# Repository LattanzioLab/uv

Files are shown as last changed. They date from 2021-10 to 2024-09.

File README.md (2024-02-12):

# Active regulation of Ultraviolet (UV) light by wildlife
Collection of materials relevant to our ongoing research testing hypotheses about UV light regulation in reptiles. 

In brief, almost a century of ecological and evolutionary studies have established the importance of daily behaviors like basking and shuttling (movements between sun and shade) by lizards and other ectotherms for maintaining thermal homeostasis. That is, for regulating their internal body temperatures. In fact, those behaviors have become synonymous with temperature regulation--so much that they are putatively referred to as 'thermoregulatory behavior.' 

Put differently, an assumption underlying approaches thus far is that the only important function of those behaviors is temperature regulation. Aside from a few studies aimed at a zoo-based audience, consideration for the importance of other functions, has remained ignored. Our goal is to promote appreciation and further study of one function in particular: <b><i>regulation of UV light exposure. </b></i>

<b>Why UV?</b>

UV exposure stimulates endogenous production of vitamin D3 (Holick et al. 1995). Lizard skin contains the precursor for vitamin D3, and initiation of the conversion process requires sun exposure (Holick et al. 1995), and the amount of vitamin D3 produced depends on the extent of UV exposure (Karsten et al. 2009). The importance of maintaining appropriate circulating vitamin D3 levels extends to multiple fitness-relevant considerations, including bone development, organ function, embryogenesis and eggshell development, to name a few (Stumpf 1988; Laing and Fraser 1999; Ferguson et al. 1996). For example, in a pivotal study by Ferguson et al. (1996) on panther chameleons (Furcifer pardalis), only females that were provided access to sufficient UV light sources produced eggs that developed to term and hatched successfully. Although reptiles can also obtain vitamin D3 via ingestion, efficacy of increasing the circulating concentration of vitamin D3 is greatest with solar UV exposure (Acierno et al. 2006); dietary D3 supplements alone are insufficient (Ferguson et al. 1996). At the same time, just as with temperature, prolonged exposure to extreme UV levels can be lethal (Ferguson et al. 1996). These considerations support that regulation of UV exposure within an optimal range should be adaptive. 

We capitalize on a classic framework (Hertz et al. 1993) for evaluating active temperature regulation in ectotherms ("cold-blooded" animals), Arduino-based electronic sensors and other components, and our lab's 3D printer, to study active UV regulation in those species. 

Please reach out if you have any questions about the materials in this repository, and also make sure to follow license and attribution guidance too (see LICENSE files); and cite this repository and related publications in your works. Thanks so much!  

Cheers,
The Lattanzio Lab

<b>  </b>
<b>REFERENCES</b>

Acierno, M.J., Mitchell, M.A., Roundtree, M.K., Zachariah, T.T. (2006). Effects of ultraviolet radiation on 25-hydroxyvitamin D3 synthesis in red-eared slider turtles (Trachemys scripta elegans). American Journal of Veterinary Research. 67:2046-2049. 

Ferguson, G.W., Jones, J.R., Gehrmann, W.H., Hammack, S.H., Talent, L.G., Hudson, R.D., Dierenfeld, E.S., Fitzpatrick, M.P., Frye, F.L., Holick, M.F., Chen, T.C. (1996). Indoor husbandry of the panther chameleon Chamaeleo [Furcifer] pardalis: Effects of dietary vitamins A and D and ultraviolet irradiation on pathology and life‐history traits. Zoo Biology. 15:279-299. 

Hertz, P.E., Huey, R.B., Stevenson, R.D. (1993). Evaluating temperature regulation by field-active ectotherms: the fallacy of the inappropriate question. The American Naturalist. 142:796-818.

Holick, M.F., Tian, X.Q., Allen, M. (1995) Evolutionary importance for the membrane enhancement of the production of vitamin D3 in the skin of poikilothermic animals. Proceedings of the National Academy of Sciences. 92:3124-3126. 

Karsten, K.B., Ferguson, G.W., Chen, T.C., Holick, M.F. (2009). Panther chameleons, Furcifer pardalis, behaviorally regulate optimal exposure to UV depending on dietary vitamin D3 status. Physiological and Biochemical Zoology. 82:218-225. 

Laing C.J., Fraser, D.R. (1999). The vitamin D system in iguanian lizards. Comparative Biochemistry and Physiology Part B: Biochemistry and Molecular Biology. 123:373-379. 

Stumpf, W.E. (1988). The endocrinology of sunlight and darkness: complementary roles of vitamin D and pineal hormones. Naturwissenschaften. 75:247-251. 

# Licenses and Attribution
Software/Code released under the [MIT License][mit-license].

All other materials, including logger devices (hardware assemblies, modifications, and documentation thereof), are released under a [Creative Commons Attribution-NonCommercial-ShareAlike 4.0 International License][cc-by-nc-sa].

[][cc-by-nc-sa]

[][cc-by-nc-sa]

[mit-license]: https://opensource.org/license/mit/
[cc-by-nc-sa]: http://creativecommons.org/licenses/by-nc-sa/4.0/
[cc-by-nc-sa-image]: https://licensebuttons.net/l/by-nc-sa/4.0/88x31.png
[cc-by-nc-sa-shield]: https://img.shields.io/badge/License-CC%20BY--NC--SA%204.0-lightgrey.svg

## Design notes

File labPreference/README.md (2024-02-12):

# Introduction
Code and documentation for a hardware assembly to record Ultraviolet (UV) light preferences for a small bodied animal (e.g., a lizard) in a laboratory preference arena (sensu Conley and Lattanzio 2022, Functional Ecology). The program is currently set to record UV exposures (in raw counts, volts, and if desired, UV Index units) at 30 second intervals for a one-hour (60 min) period, which is standard in my field. However, all parameters are user-defined and can be adjusted to meet your experimental needs. Calculations of UV Index require calibration of the sensor (Adafruit GUVA-S12SD breakout board) to UV Index values produced by a standard (e.g., Solarmeter 6.5r handheld sensor) under the lighting used in the arena (different UV bulbs produce different UV output spectra!) prior to use. The equation of the best-fit line set to zero intercept between the readings of the sensor and the standard can be used to convert future sensor readigns to UV Index. This sensor typically calibrates well to Solarmeter readings under various light sources (publication forthcoming; R^2 is typically >0.9). 

# License and Attribution
Code in this folder falls under the MIT license, and all other materials, including the UVI Preference Logger assembly and related documentation, are under a CC-BY-NC-SA license. Complete license and attribution details are provided in the main UV project [Readme.md][readme-main] file for my research lab, currently located in LattanzioLab/uv. Please review this information, and feel free to reach out with any questions/concerns. 

[readme-main]: https://github.com/LattanzioLab/uv/blob/main/README.md

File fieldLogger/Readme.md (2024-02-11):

# Introduction
In this folder you will find documentation and program code for a hardware assembly designed to record ultraviolet (UV) light exposure at user-defined intervals over various lengths of time. Logging intervals can range from seconds to hours, depending on resistor settings on the included power timer. Tests of logging duration thus far support continuous usage for several months at a one-minute logging interval on a 1000mAh lithium battery is possible. Analog readings (counts) from the attached UV sensor are converted to mV via an equation in the code; because the device runs off battery power in a field setting, calculations are made relative to a VCC reference analog pin reading. Data are logged to a microSD card in a format determined by the user (via use or modification of the supplied software code), and can then easily be brought into any spreadsheet or statistical software for analysis. 

The logger can be activated by plugging the lithium battery into the JST connector port on the power timer (see Fritzing_visual.png); once plugged in, the system will run indefinitely, logging at timer-set intervals, until the battery drains or the user unplugs the battery from that connector. In brief, at a timer interval, the timer allows power from the battery to reach the microcontroller and the logger code is run, taking a reading from the UV sensor and a time of reading from a real-time clock module, and saving those data to a CSV file on the microSD card. After the file is written, the program sends a signal to a pin on the power timer, signalling it to cut power to the microcontroller until the next interval arrives. See attached code for details. 

# Obtaining UV data from the Field UV Data Logger
Conversion of mV values to [UV Index][uv-index] requires the user to perform an initial calibration test whereby values obtained by the GUVA-S12SD sensor are compared to values obtained by an NIST Traceable standard in the field; I recommend the [Solarmeter 6.5r][solarmeter-65r] handheld UVI sensor because it senses UV exposure in the range relevant for vitamin D synthesis in reptiles. This sensor has also been used in scientific studies to explore patterns of reptile exposure in the wild: data from those studies were used to establish the Ferguson Zones well-known in the pet trade and zoological world. Once a sufficient amount of readings (I recommend at least 20 readings) are taken across a representative range of UV Index values (e.g., 0 - 12 for studies done in the US), the user should run a linear regression in the form of Y ~ X, where Y = Solarmeter UV Index reading and X = Field UV Data Logger UV sensor reading (in mV), with the intercept set to zero (zero UVI should result in zero mV). The equation of this line can then be used to convert future mV readings by the logger in that environment to UV Index values. I recommend calibrating the sensor to each new environment until we have a better understanding about the extent of geographic variation in sensor readings. 

# Importance
UV information is hard to come by in a field study, outside of weather stations which are innappropriate for studies of moving organisms in a behavioral regulation context (i.e., one needs to deploy several data loggers throughout a study locality to capture variation in conditions, not a single (often very expensive) weather station sensor). Thus, until this logger, <b>scientists have had no means to record long-term UV exposures for lizards (or other wildlife) </b>, yet these data are crucial for determining whether the animals of interest are actively, behaviorally regulating their UV exposure in the wild. My lab has tested these loggers since my initial design in various field settings and elevations in Arizona USA, revealing for the first time that lizards can and do actively regulate their UV exposure. Our findings also suport that habitat selection and use may be more strongly driven by UV costs/constraints than temperature! These findings alone have big implications for our understanding of everything from daily activity to evolutionary adaptation in these charismatic organisms. My lab will continue to investigate UV regulation in a diverse array of reptiles, and now you can too! 

Details on logger housing components (3D printed and otherwise), as well as sample calibrations and output, will be shared publicly as well once the accompanying manuscript is published; a PDF of the manuscript and other supplementary materials will be linked as well. This repository is an initial effort to ensure that others can rely on my logger assemblies and give credit to my work in advance of that publication. 

Stay tuned for more from my research lab as the story continues to unfold! 

# License Information
Code in this folder falls under the MIT license, and all other materials (i.e., Field UV Data Logger assembly and documentation) are under a CC-BY-NC-SA license. Complete license and attribution details are provided in the main UV project [Readme.md][readme-main] file for my research lab, currently located in LattanzioLab/uv. Please review this information, and feel free to reach out with any questions/concerns. 

[readme-main]: https://github.com/LattanzioLab/uv/blob/main/README.md
[solarmeter-65r]: https://www.solarmeter.com/product/model65r/
[uv-index]: https://www.cpc.ncep.noaa.gov/products/stratosphere/uv_index/uv_information.shtml

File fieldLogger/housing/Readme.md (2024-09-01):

Files needed for the 3D printable housing components for the UV data logger as described in Lattanzio (2024) Methods in Ecology and Evolution. A detailed build guide is provided in the supporting information of that paper. Part numbers are to ensure consistency with labels included in Figure 2 of main paper and supporting information.

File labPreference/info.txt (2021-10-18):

Contains program code, Fritzing diagram, Circuit diagram, and case STL model files for homemade UV preference logger. Our logger has six sensors to match the experimental arena in our laboratory. This arena has the following dimensions: overall dimensions: 91 cm × 60 cm × 20.5 cm; lane dimensions: 91 cm × 10 cm × 20.5 cm; both L × W × H. The methodology employed in our code was designed to match our methods assessing temperature regulation behavior in the same arena. In effect, we are taking advantage of a classic approach in thermal biology to evaluate UV regulation in the lab by lizards. 

Our data logger relies on:

-Adafruit GUVA-S12SD analog UV sensor breakout: https://www.adafruit.com/product/1918
-Arduino Pro Mini 3.3V: https://www.arduino.cc/en/pmwiki.php?n=Main/ArduinoBoardProMini
-Adafruit microSD breakout: https://www.adafruit.com/product/254
-Small speaker: https://www.amazon.com/Uxcell-a15080600ux0275-Internal-Magnet-Speaker/dp/B0177ABRQ6/
-Battery jumper (9V, or a 3-AA holder will work as well): https://www.amazon.com/DZS-Elec-Battery-Connector-Experimental/dp/B07FDYVD11/

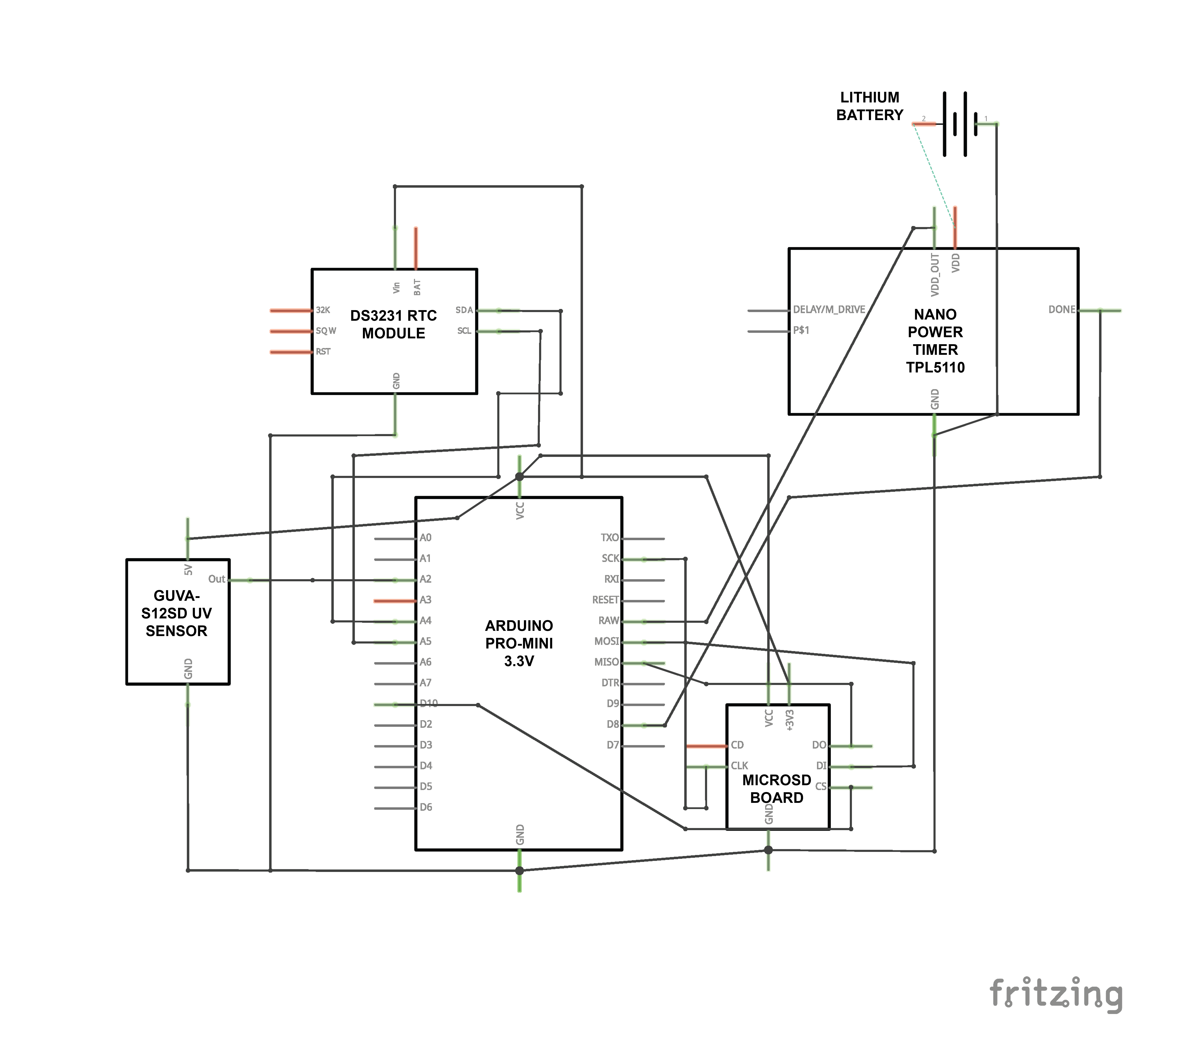
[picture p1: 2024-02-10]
fieldLogger/Fritzing_schematic.png

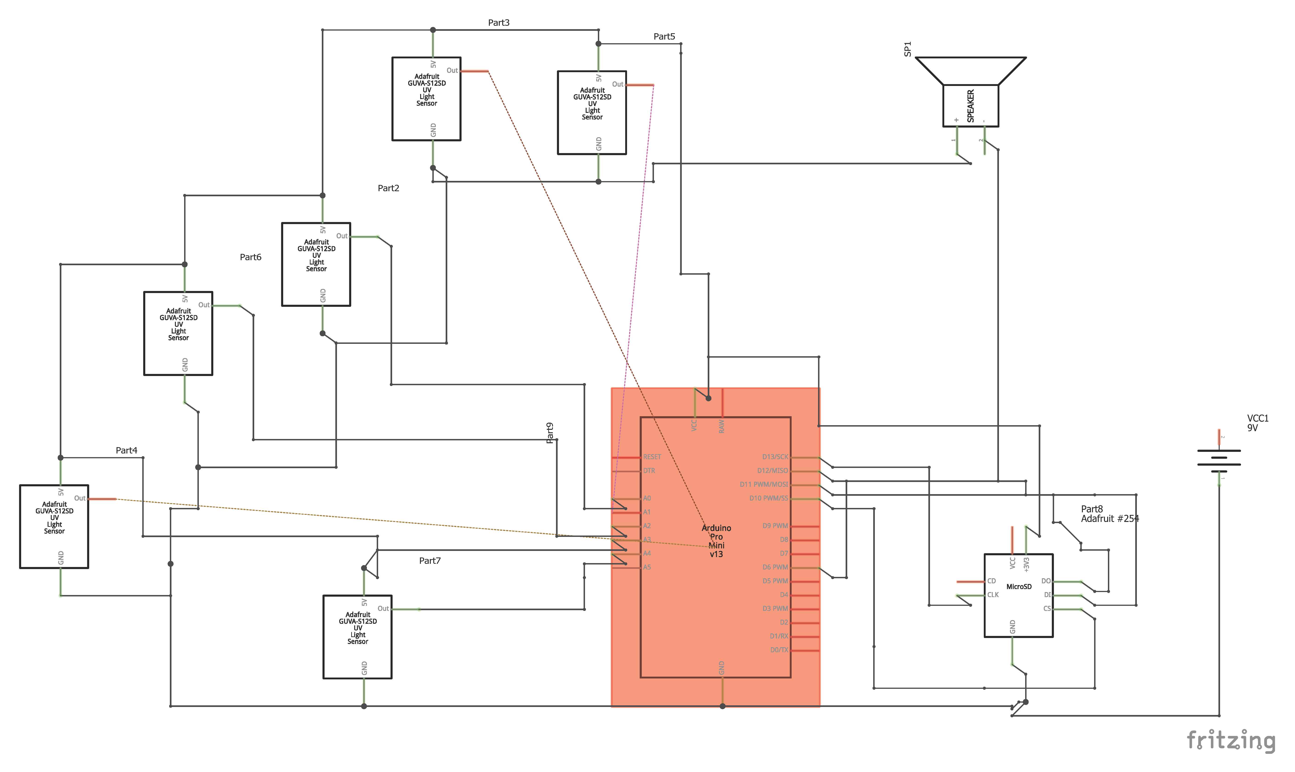
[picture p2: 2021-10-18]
labPreference/UVI preference logger - Fritzing circuit diagram.tif

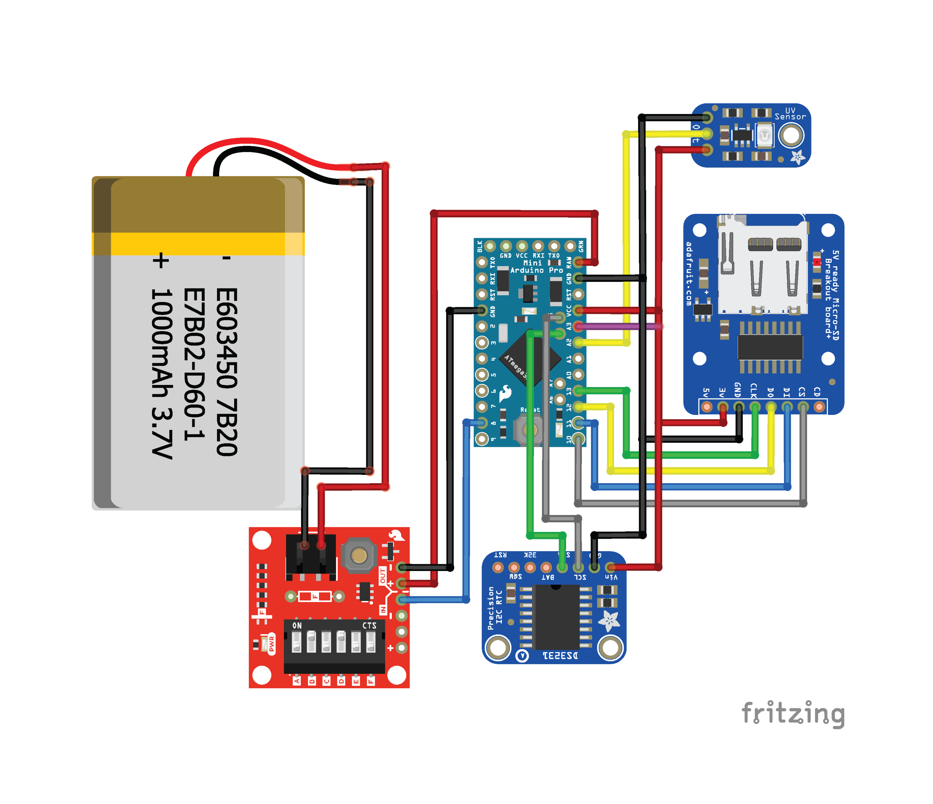
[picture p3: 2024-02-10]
fieldLogger/Fritzing_visual.png

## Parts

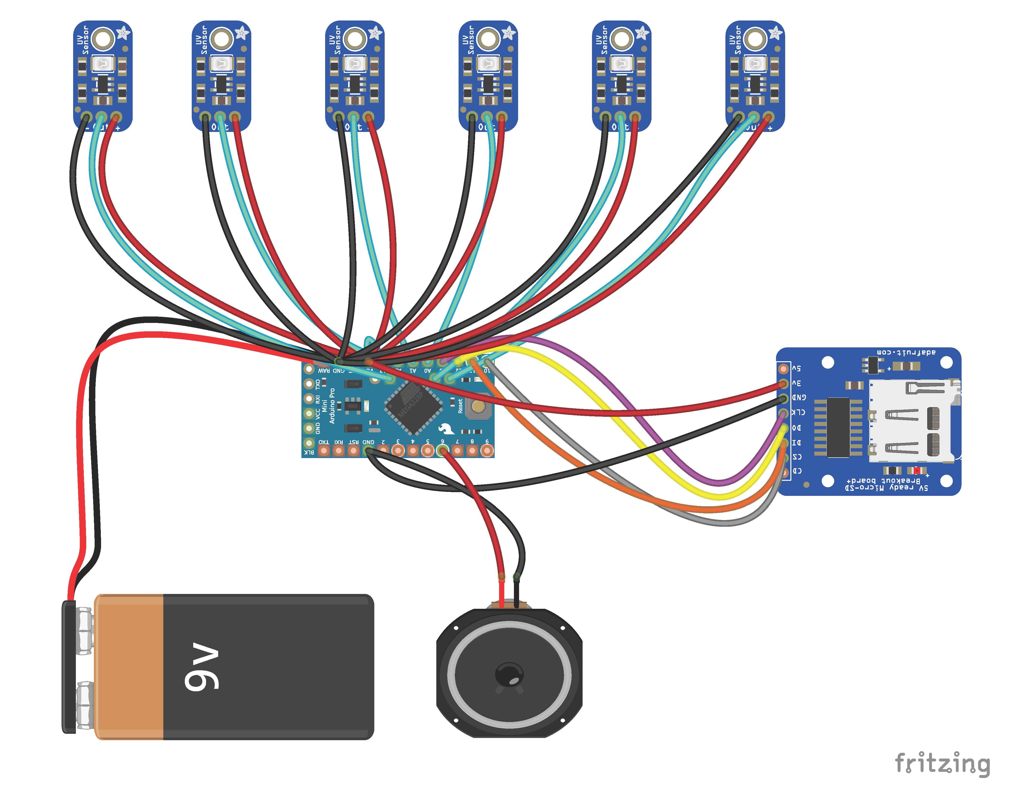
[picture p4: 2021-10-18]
labPreference/UVI preference logger - Fritzing component diagram.tiff

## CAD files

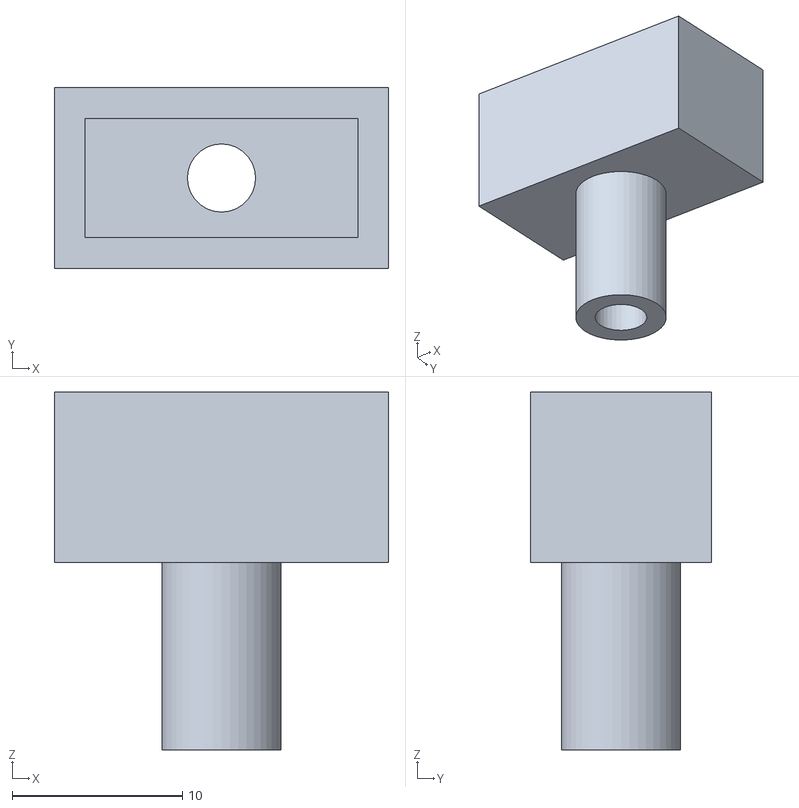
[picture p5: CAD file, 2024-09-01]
fieldLogger/housing/4-TPU-wire_adapter.stl
19.6 x 10.6 x 21.0

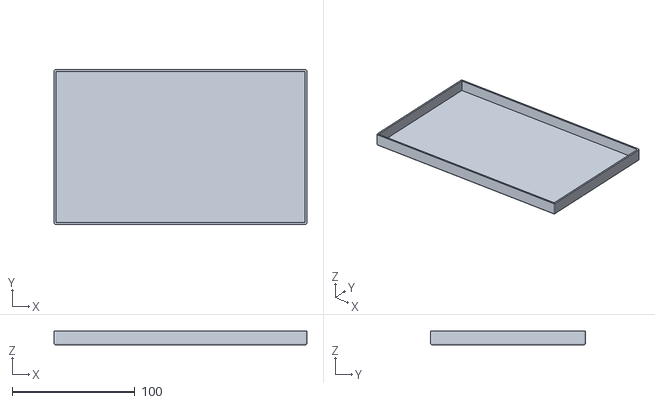
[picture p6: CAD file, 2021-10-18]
labPreference/UVI preference logger - lid.stl
206.5 x 126.5 x 11.5

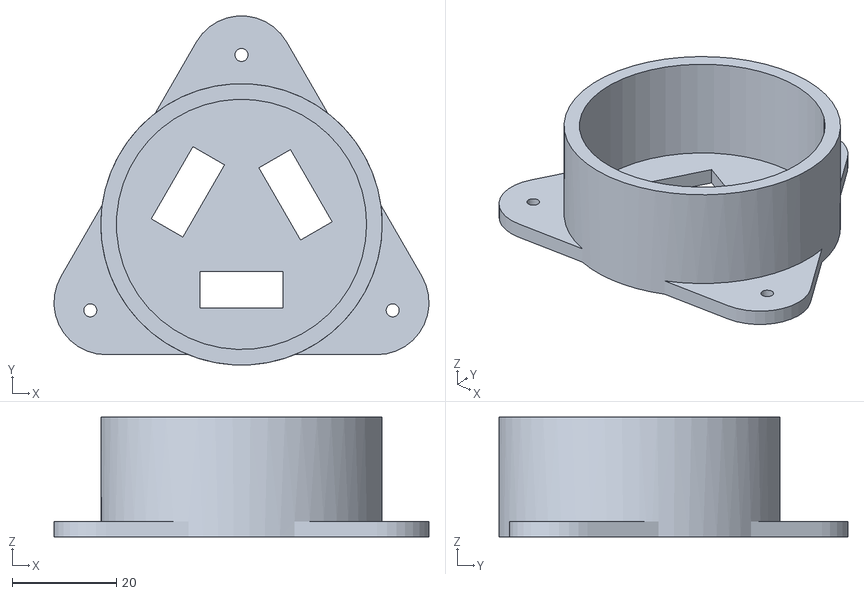
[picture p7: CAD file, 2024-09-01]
fieldLogger/housing/1-TPU-cap_3openings.stl
71.9 x 66.9 x 23.0

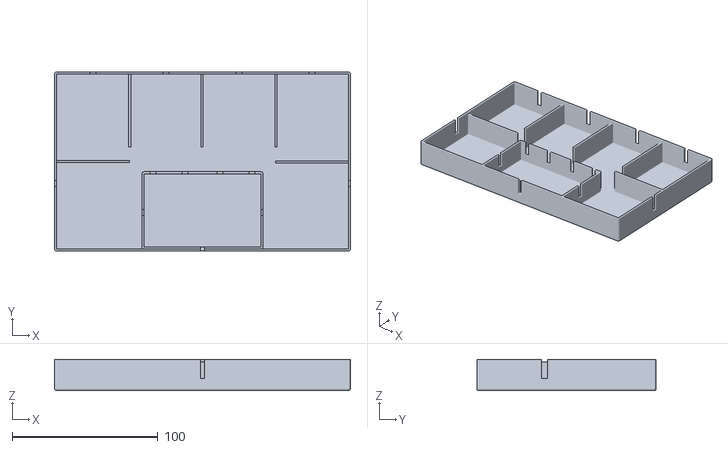
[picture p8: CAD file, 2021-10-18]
labPreference/UVI preference logger - base.stl
203.0 x 123.0 x 21.5

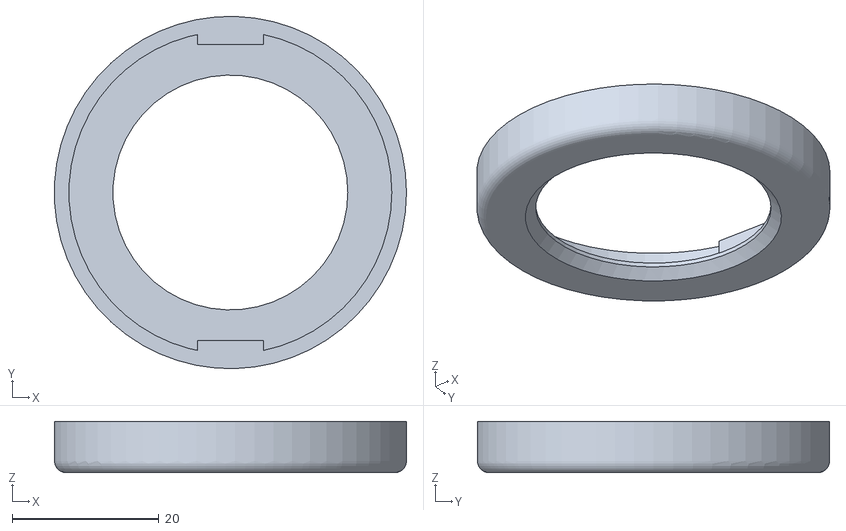
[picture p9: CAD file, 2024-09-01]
fieldLogger/housing/3-TPU-sensor_lid.stl
48.0 x 48.0 x 7.00

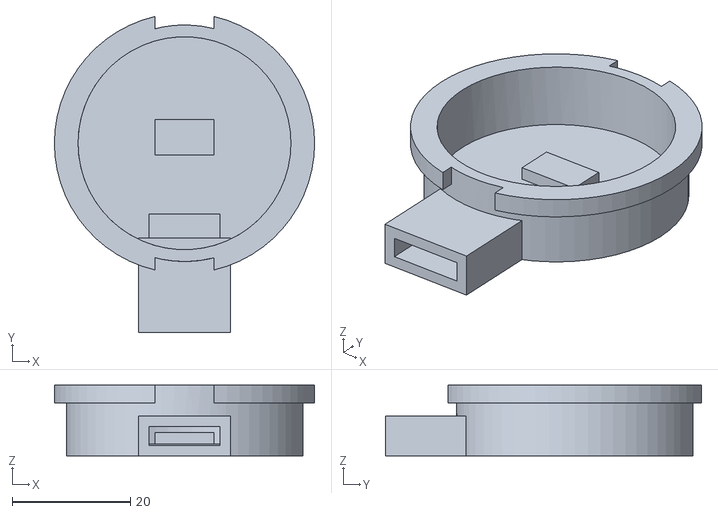
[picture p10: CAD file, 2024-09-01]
fieldLogger/housing/7-PLA-sensor_base.stl
44.0 x 53.4 x 12.0

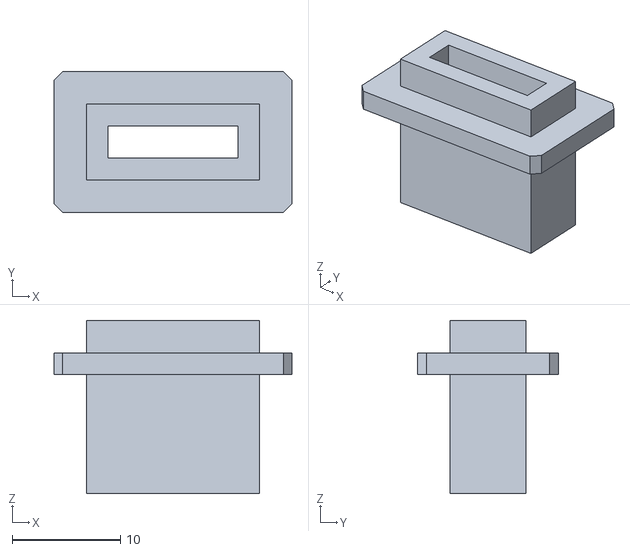
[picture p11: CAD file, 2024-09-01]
fieldLogger/housing/8-PLA-plastic_frame.stl
22.0 x 13.0 x 16.0

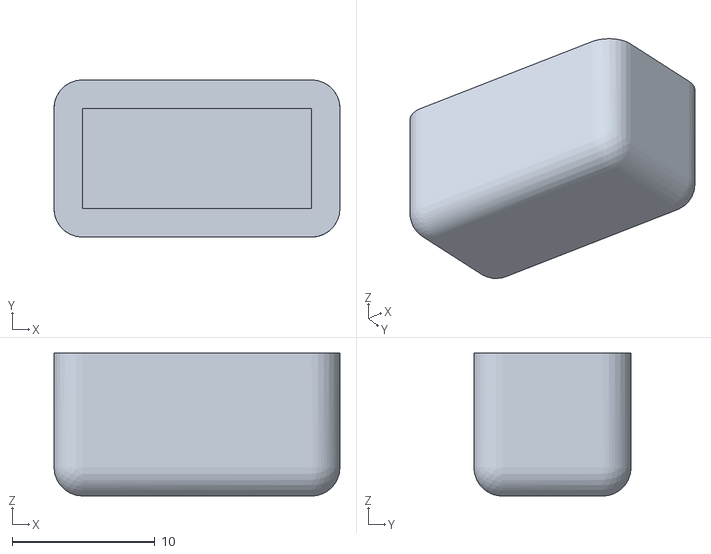
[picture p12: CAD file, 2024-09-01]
fieldLogger/housing/5-TPU-frame_cap.stl
20.0 x 11.0 x 10.0

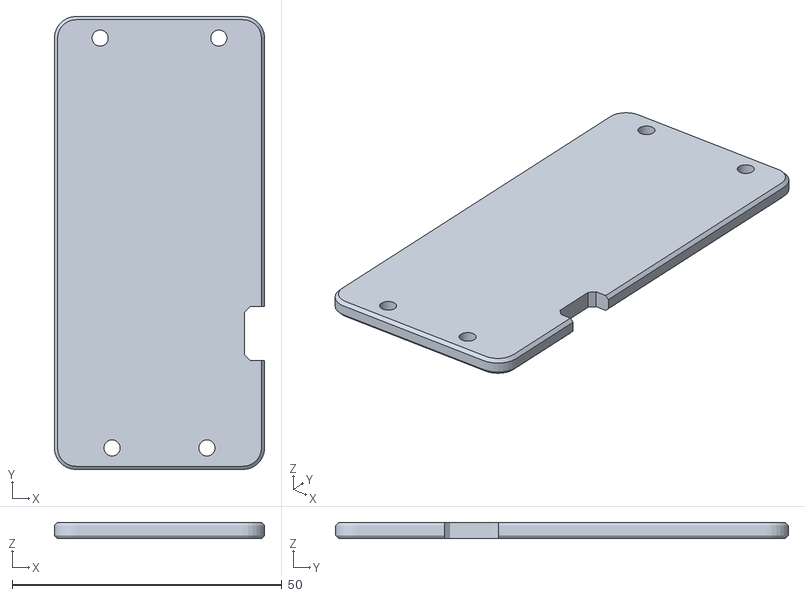
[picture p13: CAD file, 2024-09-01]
fieldLogger/housing/6-PLA-plastic_plate.stl
39.0 x 84.0 x 3.00

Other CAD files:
fieldLogger/housing/2-TPU-cap_no openings.stl

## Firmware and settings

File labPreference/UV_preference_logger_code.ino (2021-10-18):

/*Program code for lab UV preference logger for small-bodied animals. The code here was used for
 * Conley & Lattanzio's study on UV and temperature regulation in lizards. 
 * Components used: Arduino Pro-Mini 3.3V [1], Adafruit Analog GUVAS12-SD Breakout board [6], 
 * Adafruit microSD Breakout board [1], mini speaker [1]. GUVAS12-SD boards are interfaced to the 
 * Pro Mini using magnet wires to minimize mass influences on animal behavior. A battery pack (e.g.,
 * 3-AA or 1 9V) provides power to the system. 
 * We used a 6-lane arena for estimating UV preferences with this system; your input pin numbers,
 * and sensor numbers, will vary depending on your lab set-up and available pins on your microcontroller. 
 * We affixed sensors to the dorsal surface of each lizard using surgical tape, allowing us to track real-time
 * UVI exposure values of each lizard in our arena. We set our device to record UVI values at 30-second intervals
 * over a 1-hour period (to match recordings of body temperature in another part of our experiment). 
 */
#include "SdFat.h"
  SdFat SD;
  File myFile;

  //variables used to convert analog readings to UVI values
  float dat1,dat2,dat3,dat4,dat5,dat6;
  float volt1,volt2,volt3,volt4,volt5,volt6;
  float uvi1,uvi2,uvi3,uvi4,uvi5,uvi6;
  float vref;

  //analog inputs of each lane's sensor (=pin). Our arena had 6 total lanes.
  int pin1 = A6;
  int pin2 = A4;
  int pin3 = A7;
  int pin4 = A0;
  int pin5 = A2;
  int pin6 = A1;

  //reference pin for actual battery output, which may change over time.
  int refPin = A3;
  
void setup () {
  SD.begin(10); //invokes microSD reader, which is connected to pin 10 on Pro Mini. Change this value to your pin if needed!

  //calling the file uvdata.csv; naming is arbitrary. 
  myFile = SD.open("uvdata.csv", FILE_WRITE);

  /*generating a header for the file prior to data collection. I am detail-oriented, so I opted to save raw voltages (in mV)
   * and converted UVI values. It does not meaningfully affect the time to read + write to the card, so worth it despite 
   * their redundancies. 
   * First column is time in milliseconds, then the voltages for each lane, then the converted UVI values for each lane. 
   */
  if (myFile) {
      myFile.print("Time");
      myFile.print(',');
      myFile.print("L1_raw");
      myFile.print(',');
      myFile.print("L2_raw");
      myFile.print(',');
      myFile.print("L3_raw");
      myFile.print(',');
      myFile.print("L4_raw");
      myFile.print(',');
      myFile.print("L5_raw");
      myFile.print(',');
      myFile.print("L6_raw");
      myFile.print(',');
      myFile.print("L1_UVI");
      myFile.print(',');
      myFile.print("L2_UVI");
      myFile.print(',');
      myFile.print("L3_UVI");
      myFile.print(',');
      myFile.print("L4_UVI");
      myFile.print(',');
      myFile.print("L5_UVI");
      myFile.print(',');
      myFile.print("L6_UVI");
      myFile.println();
      myFile.close();
      } else {}
}

void loop () {
  //slight delay for sensors; can be reduced if desired (impact on measurement times is minimal). 
  delay(100);
  
  /*loop to record UV values at 30 second intervals for a 1-hour period (=120 measurements). 
   *Changing the delay changes the recording frequency, and changing the max value for i adjusts
   *the total number of measurements to be taken. 
    */
  for (int i = 0;  i <=119; i++) {

    //obtaining raw counts from each pin. 
  vref = analogRead(refPin);
  dat1 = analogRead(pin1);
  dat2 = analogRead(pin2);
  dat3 = analogRead(pin3);
  dat4 = analogRead(pin4);
  dat5 = analogRead(pin5);
  dat6 = analogRead(pin6);

  /*converting raw counds from each pin into voltages (in mV).
   * Here, we use vref, which is interfaced to VCC directly. We do this because
   * battery voltage output changes over time as the battery runs. This allows us
   * to calculate voltages using the actual output of VCC, rather than assuming
   * it remains at 1023 (the max counts input for an analog pin). IF you keep your 
   * Arduino plugged in to a constant power source, change each to: voltX = datX/1023*3.3,
   * where 'X' is the pin (and in our case, lane the sensor is used for our arena) of interest. 
   */
  volt1 = dat1/vref*3.3; 
  volt2 = dat2/vref*3.3; 
  volt3 = dat3/vref*3.3; 
  volt4 = dat4/vref*3.3; 
  volt5 = dat5/vref*3.3; 
  volt6 = dat6/vref*3.3; 

  /*Coversion factor (=slope) of mV to UVI will vary by light source. We used
   * Arcadia T5 UVB lights in this study. Change the conversion to the value
   * you calibrate for your study. 
   */
  uvi1 = 31.341*volt1; 
  uvi2 = 31.341*volt2; 
  uvi3 = 31.341*volt3; 
  uvi4 = 31.341*volt4;
  uvi5 = 31.341*volt5;
  uvi6 = 31.341*volt6;
  
  /*time to reopen the uvdata.csv file, and enter the data into the table. 
   * The numbers after each value refer to the decimal places to round to. We
   * recommend at least 4 decimals for these estimates. 
   */
  myFile = SD.open("uvdata.csv", FILE_WRITE);
  // if the file opened okay, write to it:
  if (myFile) {
      myFile.print(millis());
      myFile.print(',');
      myFile.print(volt1,8);
      myFile.print(',');
      myFile.print(volt2,8);
      myFile.print(',');
      myFile.print(volt3,8);
      myFile.print(',');
      myFile.print(volt4,8);
      myFile.print(',');
      myFile.print(volt5,8);
      myFile.print(',');
      myFile.print(volt6,8);
      myFile.print(',');
      myFile.print(uvi1,6);
      myFile.print(',');
      myFile.print(uvi2,6);
      myFile.print(',');
      myFile.print(uvi3,6);
      myFile.print(',');
      myFile.print(uvi4,6);
      myFile.print(',');
      myFile.print(uvi5,6);
      myFile.print(',');
      myFile.print(uvi6,6);
      myFile.println();
      myFile.close();
      } else {}

      //delay to establish recording intervals. We used 30 second (=30000 ms) intervals.
      delay(30000);
  }

  //Code to run once for loop has ended (AKA, all the data are recorded!). Delays are arbitrary.
  //User should power down system and retrieve data once tones sound. 
  delay(1000);

  //Plays end tones on speaker (speaker is connected to pin 6). 
  tone(6,523,300); 
  delay(500);
  tone(6,523,300);
  delay(500);
  tone(6,523,1000); 

  //Repeats tones after another 2-min delay. 
  delay(120000); 
  tone(6,523,300); 
  delay(500);
  tone(6,523,300);
  delay(500);
  tone(6,523,300); 
  delay(500);
  tone(6,523,300);

  //Repeats 2 minute delay
  delay(120000); //repeat 2-min delay. 
  
  //User should clear microSD card prior to re-inserting it for a new trial. Enjoy! 
}

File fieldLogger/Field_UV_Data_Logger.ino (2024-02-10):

/*Program code for Field UV Data Logger for recording long-term UV exposures in natural habitats for the study of behavioral UV regulation in wildlife. 
*Components used: Arduino Pro-Mini 3.3V [1], Adafruit Analog GUVAS12-SD Breakout board [1], Adafruit microSD Breakout board [1], Adafruit DS3231 Precision RTC module [1], 
*and a SparkFun Nano Power Timer [1]. A lithium polymer battery (I used 1000mAh capacity) provides power to the system. Lithium batteries are preferred for ease of connection to the power timer. 
*Recording intervals are set on the Nano Power Timer itself vial onboard resistor switches. Connection wiring is described in the images included in this repository folder. 
Additional information on the logger system and assembly is forthcoming (including housing components, calibration, and output examples).
*/

/*A note on library usage: Make sure to rely on the following library-version combinations; I have had issue with the microSD board and RTC module not working correctly with newer libraries. 
*The logger program works using the following library versions:
*SdFat version 1.1.2
*RTClib version 1.2.2
*/

//Load required libraries
#include <SPI.h>
#include "SdFat.h"
#include "RTClib.h"
#include <Wire.h>
SdFat SD;
RTC_DS3231 rtc;

//Set pins
const int chipSelect = 10; 
int donePin = 8; 
int sensorPin = A2;
int refPin = A3;

//Specify voltage and UV Index calculations below as float
float vref, countdat, voltdat, uvi;

//initiate a file for the microSD card
File myFile;

void setup() {
  SD.begin(10); //this might allow me to invoke SD directly by specifying the CS pin (when >1 SPI attached)
 // Run this section the first time you power it all up, then re-install program with this section commented out to get the RTC set up to your date/time! 
 // if (rtc.lostPower()) {  
 //  rtc.adjust(DateTime(F(__DATE__), F(__TIME__)));
 //  }

  //set the donePin as output
  pinMode(donePin, OUTPUT); 
}

void loop() {
    delay(100);
    DateTime now = rtc.now();
    delay(100);

    //obtain reference voltage from refPin (pin is connected directly to VCC so provides an analog reading of the voltage)
    vref = analogRead(refPin);
    
    //read the UV sensor
    countdat = analogRead(sensorPin);

    //convert the sensor reading to voltage
    voltdat = countdat/vref*3.3;
    uvi = 8.8529*voltdat; //This is a calibration to southeastern Arizona sunlight; replace with your own calibration results! See Readme for more infomation!

    //create and open a data file on the microSD card
    myFile = SD.open("data.csv", FILE_WRITE); //I recommend a unique name for each data logger you create [e.g., data_01.csv, data_02.csv]

/* If the file opened okay, write to it! Here I just made a column for all date/time information, the tempreature of the RTC module [to ensure it is within expected range], 
* and provide the raw sensor reading (in counts), the converted voltage (in V), and the converted UV Index value (UVI has no units).  
*/
   if (myFile) {
     myFile.print(now.year(), DEC);
     myFile.print(',');
     myFile.print(now.month(), DEC);
     myFile.print(',');
     myFile.print(now.day(), DEC);
     myFile.print(',');
     myFile.print(now.hour(), DEC);
     myFile.print(',');
     myFile.print(now.minute(), DEC);
     myFile.print(',');
     myFile.print(now.second(), DEC);
     myFile.print(',');
     myFile.print(rtc.getTemperature());
     myFile.print(',');
     myFile.print(countdat,5);
     myFile.print(',');
     myFile.print(voltdat,8);
     myFile.print(',');
     myFile.print(uvi,8);
     myFile.println();
     // close the file:
     myFile.close();
   } else {
   }
   delay(1000); 
/* Send the signal to the Timer that data collection is done for that interval; this turns off power to the microcontroller until the next interval */
   digitalWrite(donePin, LOW); 
   digitalWrite(donePin, HIGH); 
   }
